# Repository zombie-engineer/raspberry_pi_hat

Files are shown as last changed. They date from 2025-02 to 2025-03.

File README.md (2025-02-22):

Raspberry PI hat.
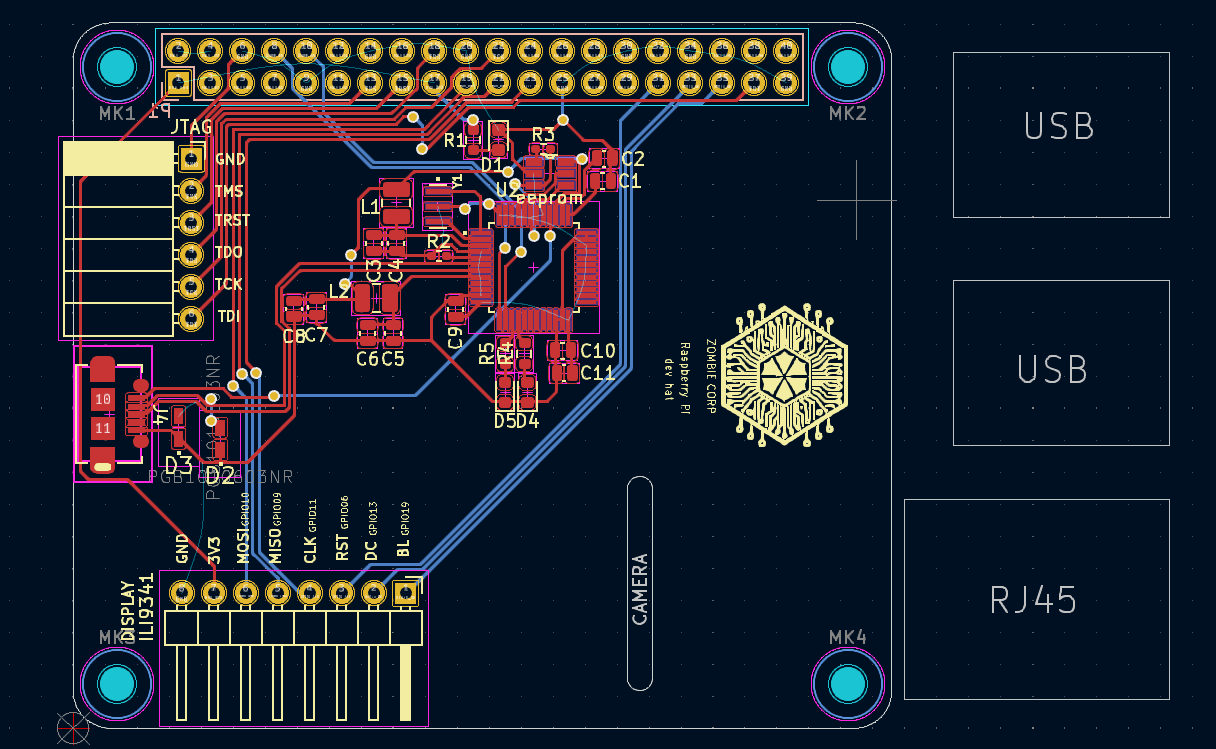
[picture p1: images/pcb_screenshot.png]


Convenience expansion board for raspberry pi development.

Features:

JTAG connector for debug
Raspberry Pi has JTAG pins, TDO, TDI, TMS, TCK, etc. They are distributed in chaotic way across pin connector.
For this reason it is good to create a nice little connector, especially designated for JTAG

Micro USB connector for uart output
Raspberry PI has special pins for UART. This pins are routed to FTDI FT232H chip, which further redirects uart
data to USB.
Datasheet for the FTDI FT232H is here:
https://ftdichip.com/wp-content/uploads/2024/09/DS_FT232H.pdf

Display connector for ILI9341 SPI Display

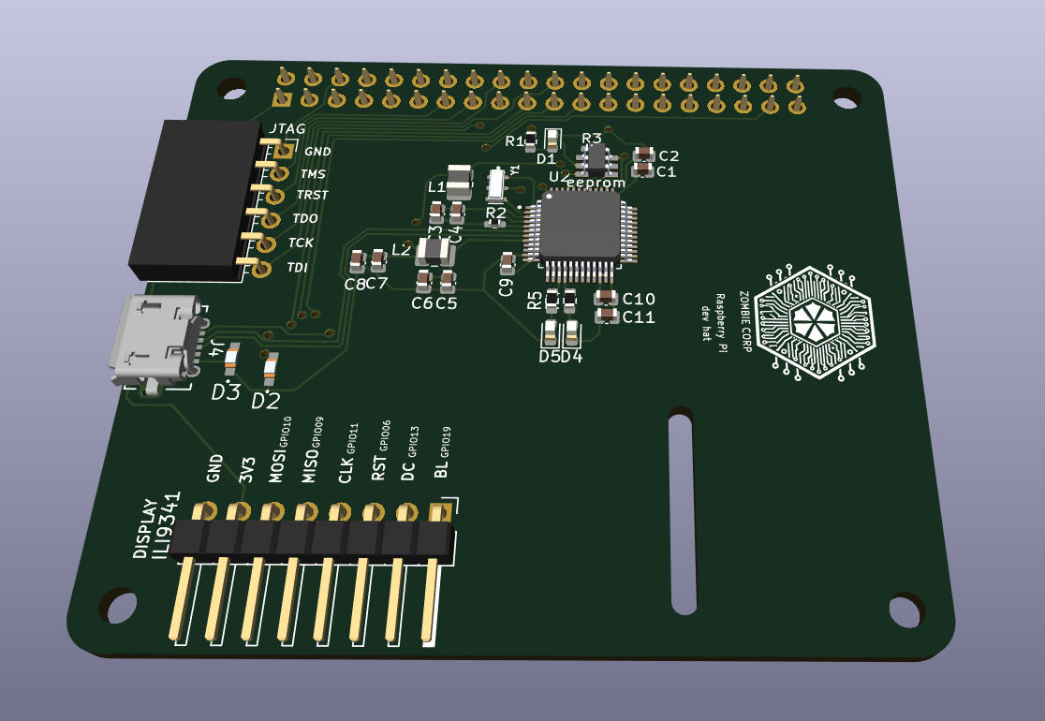
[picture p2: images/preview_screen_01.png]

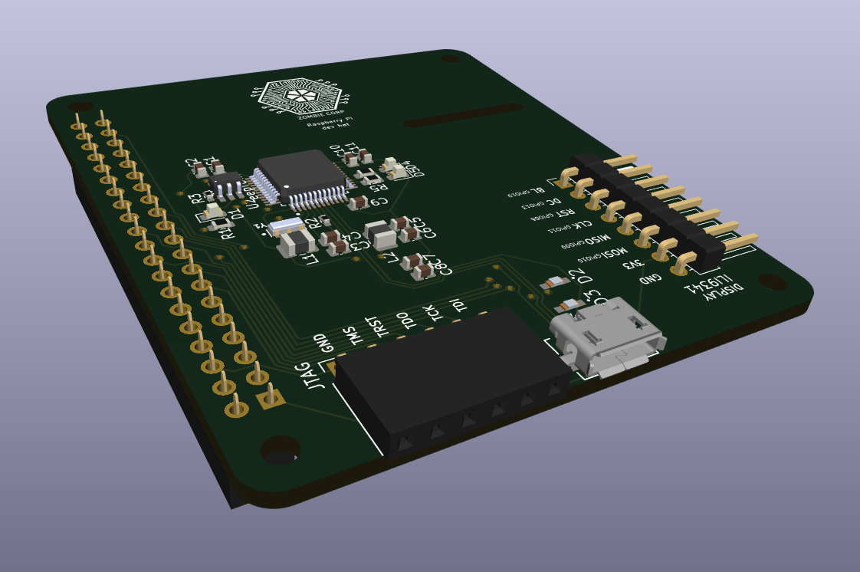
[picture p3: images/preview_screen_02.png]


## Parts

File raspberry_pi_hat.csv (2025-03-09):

Source: | /home/user_user/raspberry_pi_hat/raspberry_pi_hat.kicad_sch
Date: | Сб 08 мар 2025 21:29:07
Tool: | Eeschema 7.0.11-7.0.11~ubuntu20.04.1
Generator: | /usr/share/kicad/plugins/bom_csv_grouped_by_value_with_fp.py
Component Count: | 42
Ref | Qnty | Value | Cmp name | Footprint | Description | Vendor | DNP
C1, C2, C4, C6, C8, C9, C10, C11, C15, C16, C17 | 11 | 0.1uF | C | Capacitor_SMD:C_0201_0603Metric_Pad0.64x0.40mm_HandSolder | Unpolarized capacitor
C3, C5, C7, C14 | 4 | 4.7uF | C_Polarized | footprints:CAPPM2014X120N | Polarized capacitor
C12, C13 | 2 | 27pF | C | Capacitor_SMD:C_0201_0603Metric_Pad0.64x0.40mm_HandSolder | Unpolarized capacitor
D1, D4, D5 | 3 | LED | LED | LED_SMD:LED_0603_1608Metric | Light emitting diode
D2 | 1 | PGB1010603NR (x2) | PGB1010603NR | footprints:PGB1010603NRHF | ESD Suppressors / TVS Diodes 0603 24VDC .06pF
D3 | 1 | PGB1010603NR | PGB1010603NR | footprints:PGB1010603NRHF | ESD Suppressors / TVS Diodes 0603 24VDC .06pF
J1 | 1 | CONN_JTAG | Conn_01x06 | Connector_PinSocket_2.54mm:PinSocket_1x06_P2.54mm_Horizontal | Generic connector, single row, 01x06, script generated (kicad-library-utils/schlib/autogen/connector/)
J3 | 1 | Conn_01x08 | Conn_01x08 | Connector_PinHeader_2.54mm:PinHeader_1x08_P2.54mm_Horizontal | Generic connector, single row, 01x08, script generated (kicad-library-utils/schlib/autogen/connector/)
J4 | 1 | 105017-0001 | 475890001 | footprints:CON00363_5_MOL_FIXED
L1, L2, L4 | 3 | 600R/0.5A | L_Iron | footprints:BLM21AG102BH1J | Inductor with iron core
P1 | 1 | CONN_02X20 | CONN_02X20 | Connector_PinSocket_2.54mm:PinSocket_2x20_P2.54mm_Vertical
R1, R4, R5 | 3 | 220 | R | Resistor_SMD:R_0201_0603Metric_Pad0.64x0.40mm_HandSolder | Resistor
R2 | 1 | 12K / %1 | R | Resistor_SMD:R_0201_0603Metric_Pad0.64x0.40mm_HandSolder | Resistor
R3 | 1 | 2K2 | R | Resistor_SMD:R_0201_0603Metric_Pad0.64x0.40mm_HandSolder | Resistor
R6, R8, R9, R10 | 4 | 10K | R | Resistor_SMD:R_0201_0603Metric_Pad0.64x0.40mm_HandSolder | Resistor
R7 | 1 | 39K | R | Resistor_SMD:R_0201_0603Metric_Pad0.64x0.40mm_HandSolder | Resistor
U1 | 1 | 93LC56BT-I_OT | 93LC56BT-I_OT | footprints:SOT95P280X145-6N
U2 | 1 | FT232H | FT232H | footprints:QFP50P900X900X160-48N | Hi Speed Single Channel USB UART/FIFO, LQFP/QFN-48
Y1 | 1 | CSTNE12M0G550000R0 | CSTNE12M0G550000R0 | footprints:OSC_CSTNE12M0G550000R0

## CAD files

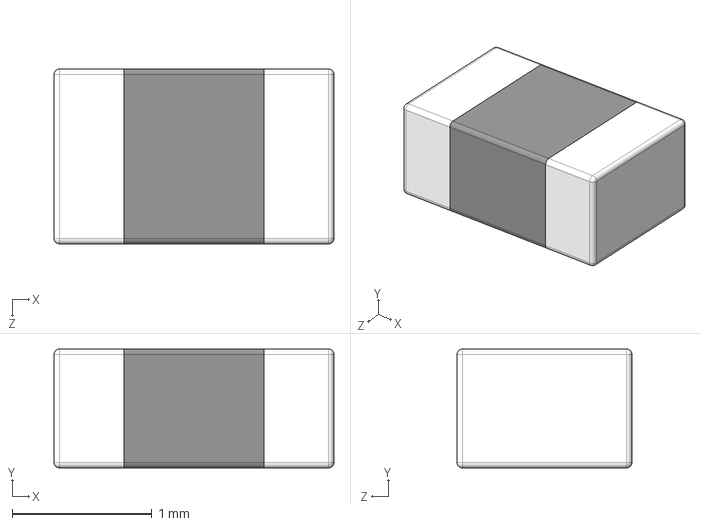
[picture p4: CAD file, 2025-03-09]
models/BLM21AG601SN1D.stp
2.00 x 0.85 x 1.25 mm

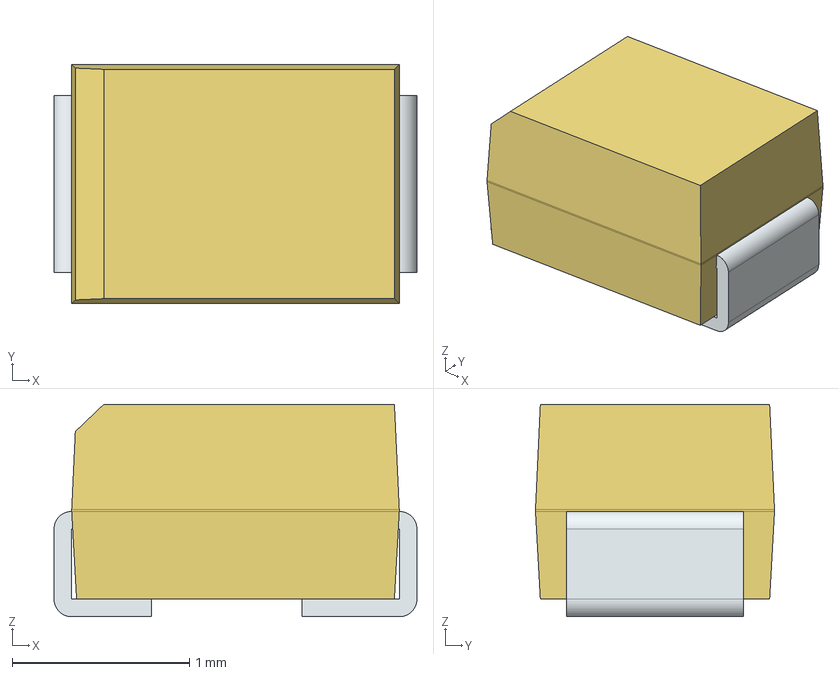
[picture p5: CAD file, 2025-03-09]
models/TAJR475M010RNJ.stp
2.05 x 1.35 x 1.20 mm
FilletPin1
FilletPin2

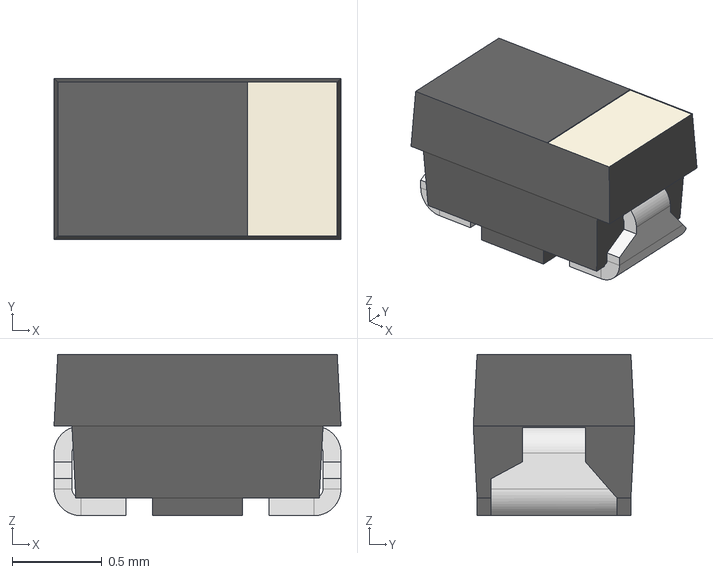
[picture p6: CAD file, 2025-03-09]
models/T55J475M6R3C0500.stp
1.60 x 0.9 x 0.9 mm
Base-2
Terminal

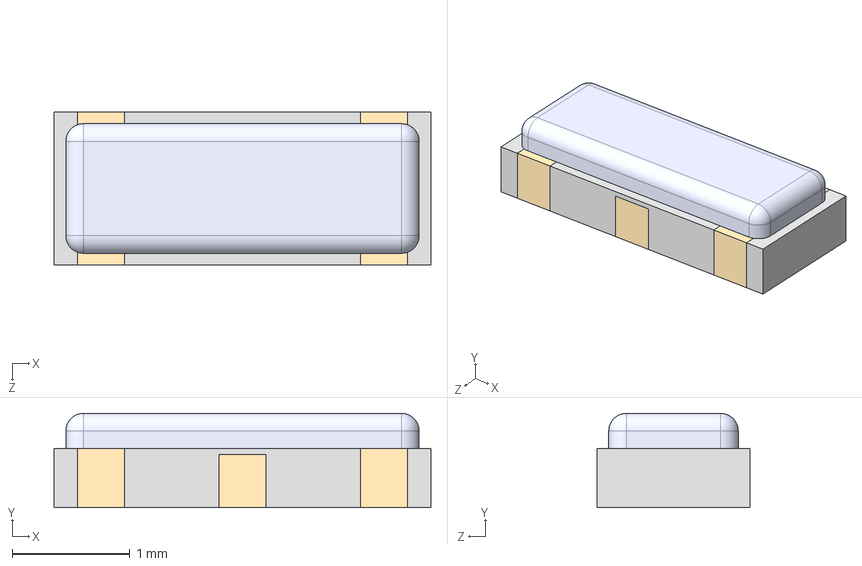
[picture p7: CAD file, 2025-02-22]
models/CSTNE12M0G550000R0.step
3.20 x 0.8 x 1.30 mm

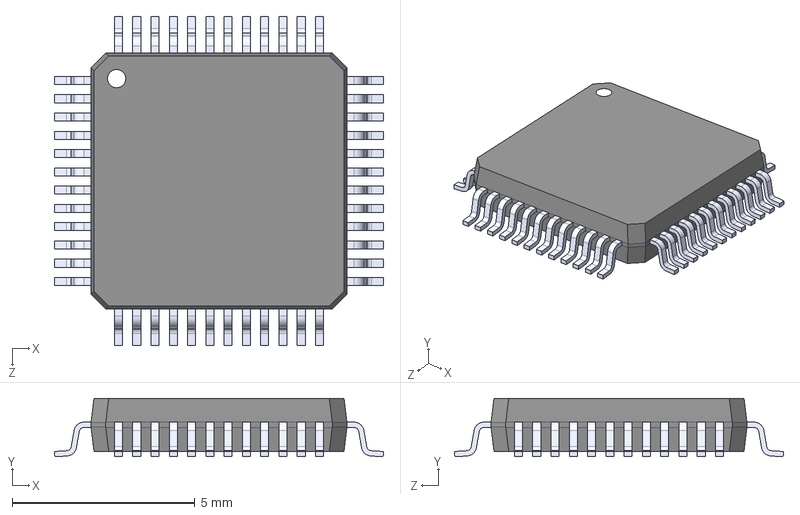
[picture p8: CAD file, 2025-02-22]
models/FT232HL-REEL.step
9.00 x 1.60 x 9.00 mm

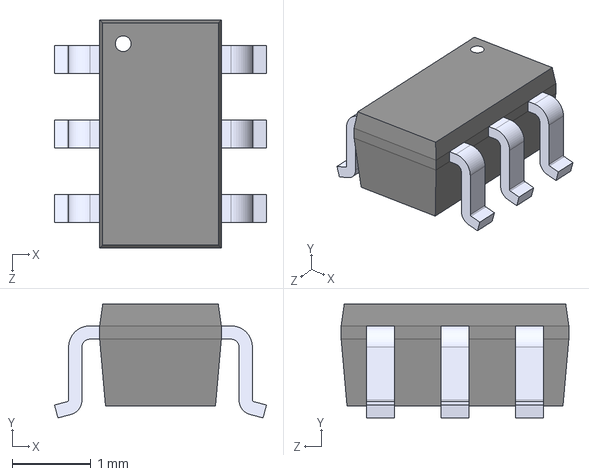
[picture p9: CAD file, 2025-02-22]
models/93LC56BT-I_OT.step
2.70 x 1.45 x 2.90 mm

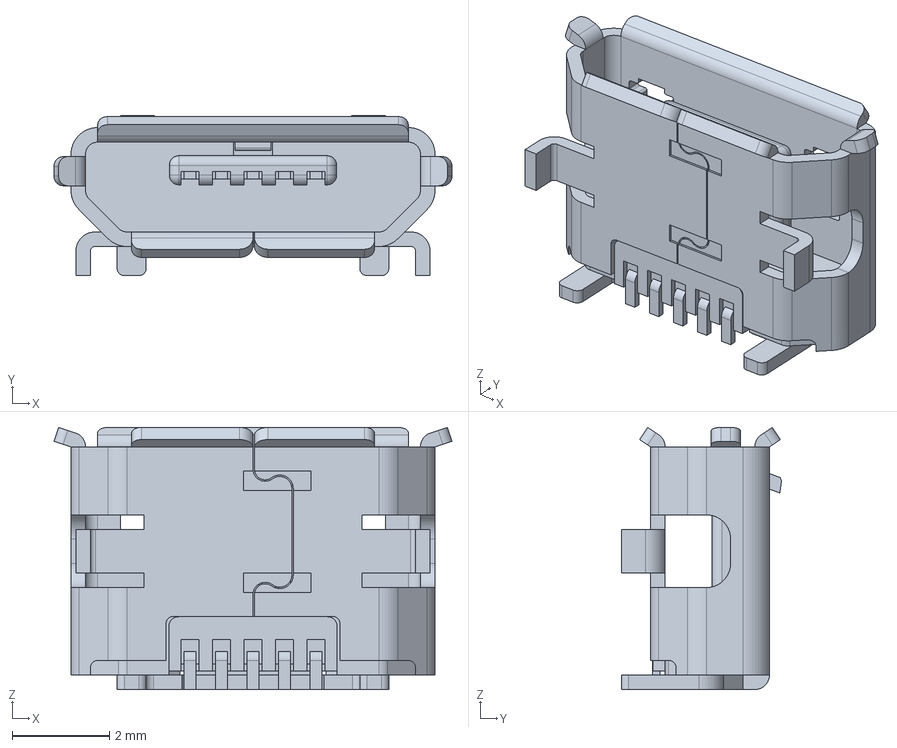
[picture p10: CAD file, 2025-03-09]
models/105017-0001.stp
8.20 x 3.30 x 5.40 mm

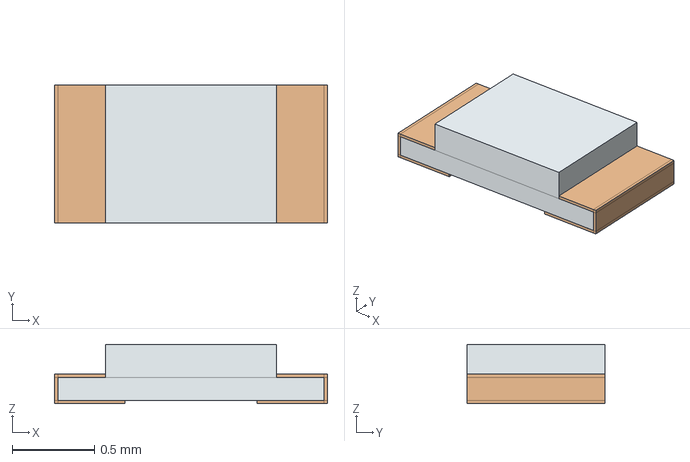
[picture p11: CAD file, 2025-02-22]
models/PGB1010603NR.stp
1.66 x 0.84 x 0.36 mm
solidBody
solidLead

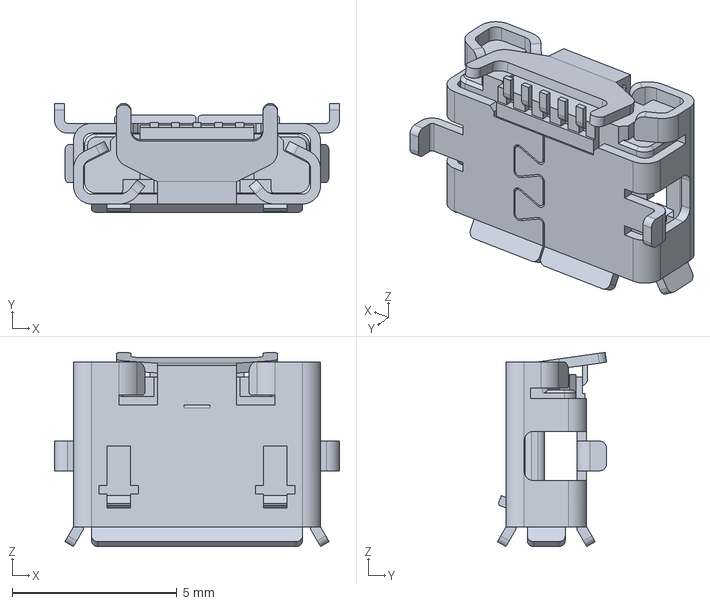
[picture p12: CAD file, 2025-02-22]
models/475890001.stp
8.65 x 3.31 x 5.89 mm

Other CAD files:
models/0475890001.stl

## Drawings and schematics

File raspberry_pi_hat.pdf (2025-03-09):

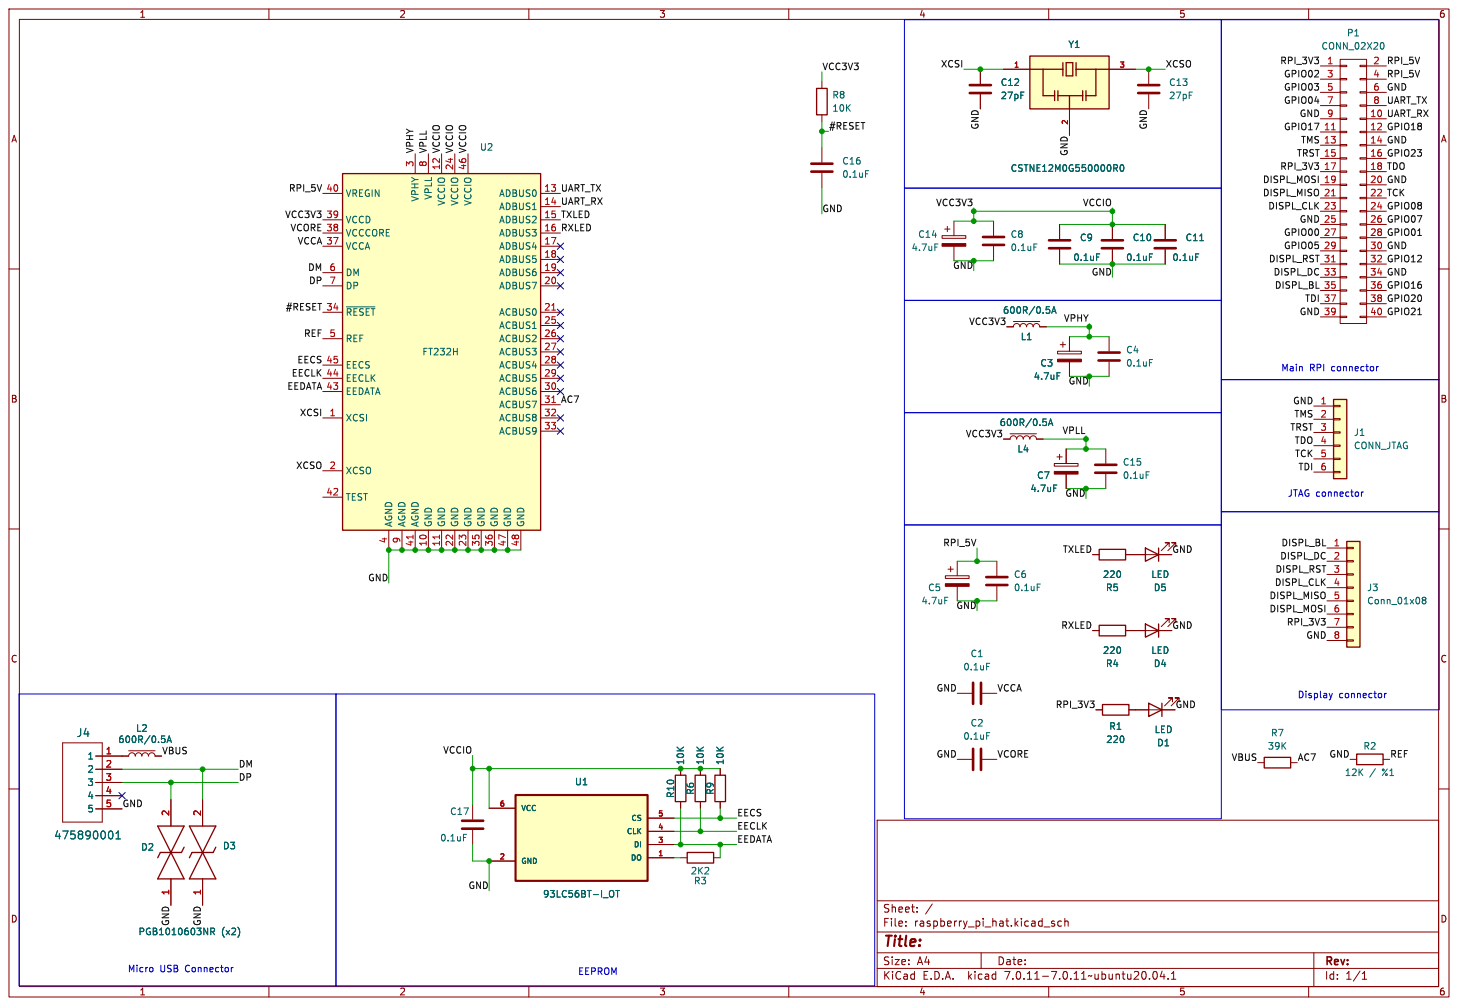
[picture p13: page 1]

4 VREGIN 40 AGND 41 TEST 42 EEDATA 43 EECLK 44 EECS 45 VCCIO 46 GND 47 GND 48 REF 5 DM 6 DP 7 VPLL

3 ACBUS6 30 ACBUS7 31 ACBUS8 32 ACBUS9 33 ~{RESET} 34 GND 35 GND 36 VCCA 37 VCCCORE 38 VCCD 39 AGND

#RESET REF DP DM

Id: 1/1 Title: File: raspberry_pi_hat.kicad_sch Sheet: /

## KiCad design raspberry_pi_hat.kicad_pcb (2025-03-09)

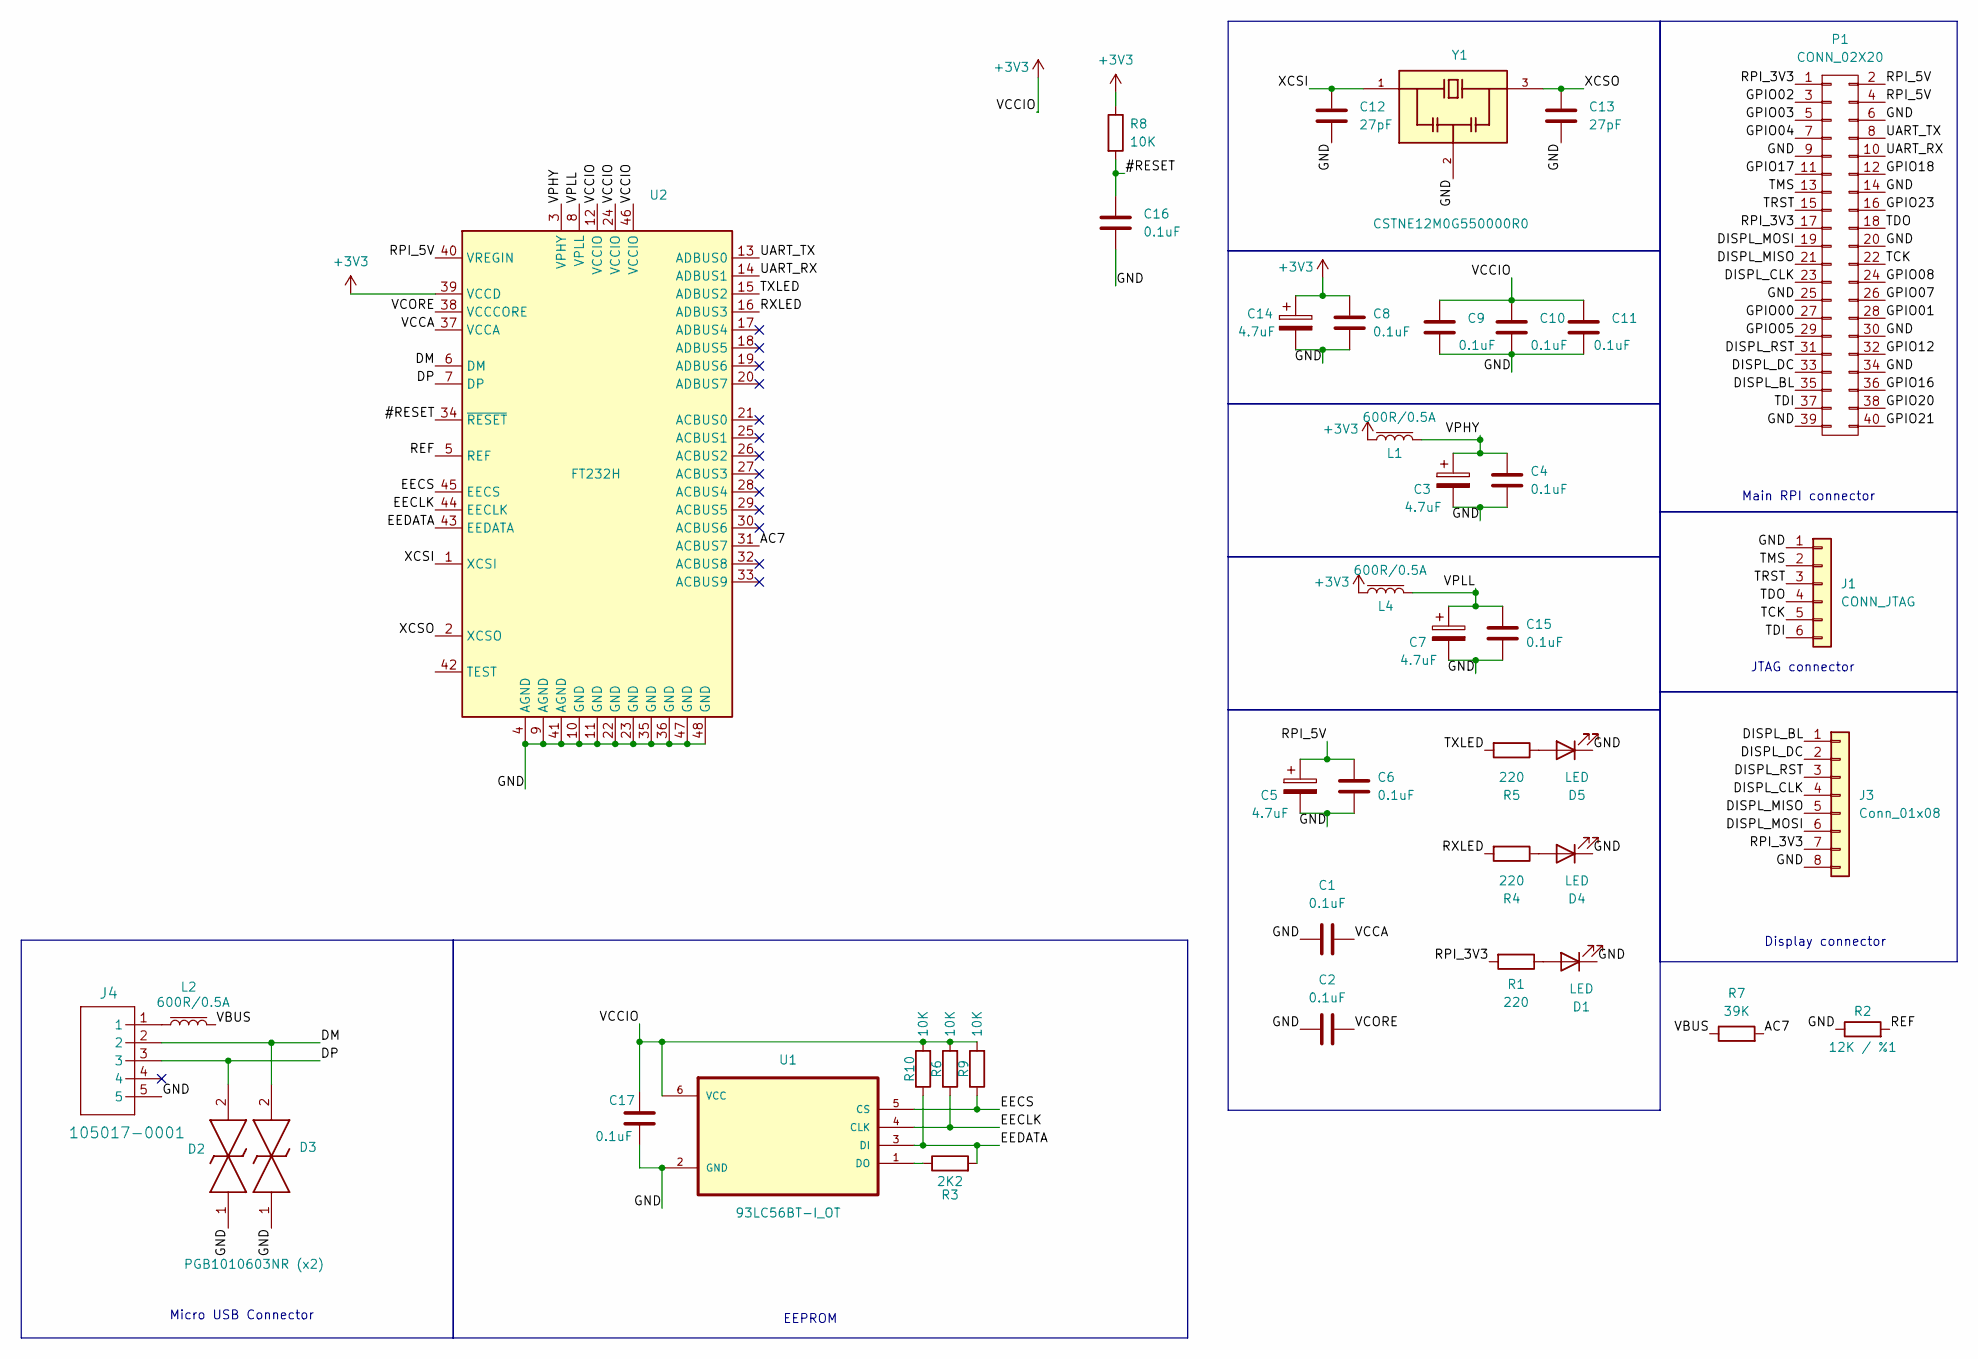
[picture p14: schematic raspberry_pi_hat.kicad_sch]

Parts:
C1, C2, C4, C6, C8, C9, C10, C11, C15, C16, C17: 0.1uF; C_0201_0603Metric_Pad0.64x0.40mm_HandSolder
C3, C5, C7, C14: 4.7uF; CAPPM2014X120N
C12, C13: 27pF; C_0201_0603Metric_Pad0.64x0.40mm_HandSolder
D1, D4, D5: LED; LED_0603_1608Metric
D2: PGB1010603NR (x2); PGB1010603NRHF; Mouser Part Number 576-PGB1010603NR
D3: PGB1010603NR; PGB1010603NRHF; Mouser Part Number 576-PGB1010603NR
J1: CONN_JTAG; PinSocket_1x06_P2.54mm_Horizontal
J3: Conn_01x08; PinHeader_1x08_P2.54mm_Horizontal
J4: 105017-0001; CON00363_5_MOL_FIXED
L1, L2, L4: 600R/0.5A; BLM21AG102BH1J
P1: CONN_02X20; PinSocket_2x20_P2.54mm_Vertical
R1, R4, R5: 220; R_0201_0603Metric_Pad0.64x0.40mm_HandSolder
R2: 12K / %1; R_0201_0603Metric_Pad0.64x0.40mm_HandSolder
R3: 2K2; R_0201_0603Metric_Pad0.64x0.40mm_HandSolder
R6, R8, R9, R10: 10K; R_0201_0603Metric_Pad0.64x0.40mm_HandSolder
R7: 39K; R_0201_0603Metric_Pad0.64x0.40mm_HandSolder
U1: 93LC56BT-I_OT; SOT95P280X145-6N
U2: FT232H; QFP50P900X900X160-48N
Y1: CSTNE12M0G550000R0; OSC_CSTNE12M0G550000R0; PARTREV JGC42-8858A

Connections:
+3V3: C8.1, C9.1, C10.1, C11.1, C14.1, C17.1, L1.1, L4.1, R6.2, R8.1, R9.2, R10.2, U1.6 (VCC), U2.12 (VCCIO), U2.24 (VCCIO), U2.39 (VCCD), U2.46 (VCCIO)
/#RESET: C16.1, R8.2, U2.34 (~RESET)
/AC7: R7.2, U2.31 (ACBUS7)
/DISPL_BL: J3.1, P1.35
/DISPL_CLK: J3.4, P1.23
/DISPL_DC: J3.2, P1.33
/DISPL_MISO: J3.5, P1.21
/DISPL_MOSI: J3.6, P1.19
/DISPL_RST: J3.3, P1.31
/DM: D3.2, J4.2, U2.6 (DM)
/DP: D2.2, J4.3, U2.7 (DP)
/EECLK: R6.1, U1.4 (CLK), U2.44 (EECLK)
/EECS: R9.1, U1.5 (CS), U2.45 (EECS)
/EEDATA: R3.2, R10.1, U1.3 (DI), U2.43 (EEDATA)
/GND: C1.1, C2.1, C3.2, C4.2, C5.2, C6.2, C7.2, C8.2, C9.2, C10.2, C11.2, C12.1, C13.1, C14.2, C15.2, C16.2, C17.2, D1.1 (K), D2.1, D3.1, D4.1 (K), D5.1 (K), J1.1, J3.8, J4.5, P1.6, P1.9, P1.14, P1.20, P1.25, P1.30, P1.34, P1.39, R2.1, U1.2 (GND), U2.4 (AGND), U2.9 (AGND), U2.10 (GND), U2.11 (GND), U2.22 (GND), U2.23 (GND), U2.35 (GND), U2.36 (GND), U2.41 (AGND), U2.47 (GND), U2.48 (GND), Y1.2
/GPIO00: P1.27
/GPIO01: P1.28
/GPIO02: P1.3
/GPIO03: P1.5
/GPIO04: P1.7
/GPIO05: P1.29
/GPIO07: P1.26
/GPIO08: P1.24
/GPIO12: P1.32
/GPIO16: P1.36
/GPIO17: P1.11
/GPIO18: P1.12
/GPIO20: P1.38
/GPIO21: P1.40
/GPIO23: P1.16
/REF: R2.2, U2.5 (REF)
/RPI_3V3: J3.7, P1.1, P1.17, R1.2
/RPI_5V: C5.1, C6.1, P1.2, P1.4, U2.40 (VREGIN)
/RXLED: R4.2, U2.16 (ADBUS3)
/TCK: J1.5, P1.22
/TDI: J1.6, P1.37
/TDO: J1.4, P1.18
/TMS: J1.2, P1.13
/TRST: J1.3, P1.15
/TXLED: R5.2, U2.15 (ADBUS2)
/UART_RX: P1.10, U2.14 (ADBUS1)
/UART_TX: P1.8, U2.13 (ADBUS0)
/VBUS: L2.2, R7.1
/VCCA: C1.2, U2.37 (VCCA)
/VCORE: C2.2, U2.38 (VCCCORE)
/VPHY: C3.1, C4.1, L1.2, U2.3 (VPHY)
/VPLL: C7.1, C15.1, L4.2, U2.8 (VPLL)
/XCSI: C12.2, U2.1 (XCSI), Y1.1
/XCSO: C13.2, U2.2 (XCSO), Y1.3
unnamed: D1.2 (A), R1.1
unnamed: D4.2 (A), R4.1
unnamed: D5.2 (A), R5.1
unnamed: J4.1, L2.1
unnamed: R3.1, U1.1 (DO)

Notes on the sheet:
Display connector
EEPROM
Main RPI connector
Micro USB Connector
JTAG connector

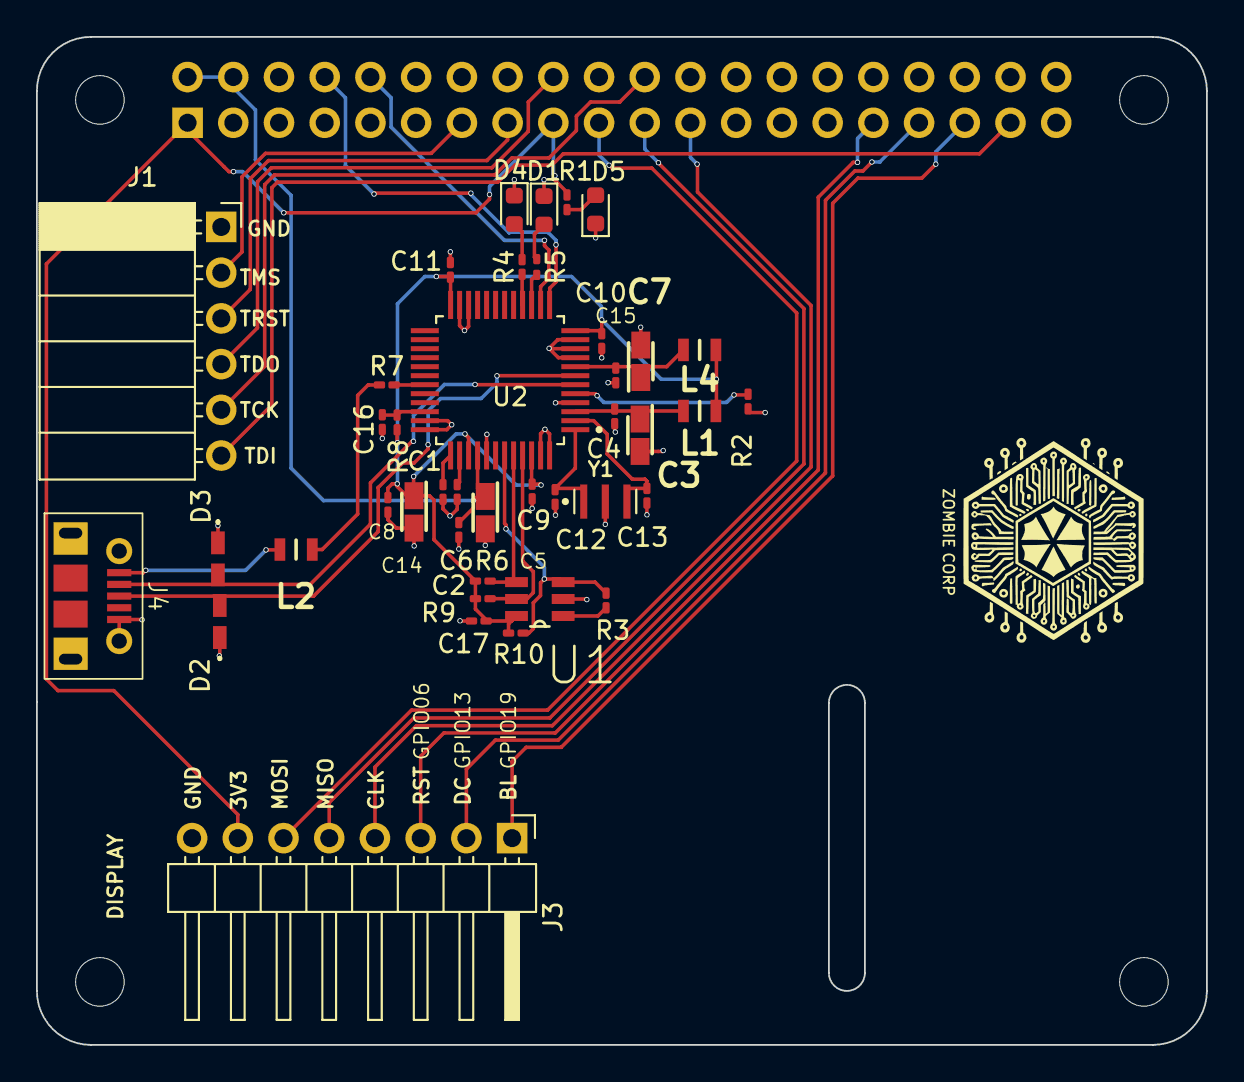
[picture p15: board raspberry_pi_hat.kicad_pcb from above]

Board: 2 copper layers, 65.0 x 56.0 mm, 46 parts (1 on the bottom side), 39 nets.

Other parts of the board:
MK1, MK2, MK3, MK4: M2.5; MountingHole_2.7mm_M2.5
